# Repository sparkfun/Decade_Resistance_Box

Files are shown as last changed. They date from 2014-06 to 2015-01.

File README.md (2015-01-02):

Decade Resistance Box - KIT-13006
========================================

[Decade Resistance Box 
KIT-13006](https://www.sparkfun.com/products/13006)

This repository is for a decade resistance box kit, adjustable between 0 Ohms and 999,990 Ohms in 10 Ohm steps.  [More information can be found here.](https://www.sparkfun.com/products/13006)

Detailed information about building and using the decade resistance can be found it it's [hookup guide](https://learn.sparkfun.com/tutorials/decade-resistance-box-hookup-guide). 

This part was created in Eagle v6.5.0.  
The front panel etching/overlay was created with Inkscape 0.48.

Repository Contents
-------------------

* **/Hardware** - All Eagle design files (.brd, .sch, .STL)
* **/case-label** - The front panel markings in PDF and multi-layer SVG formats. 
* **/tutorial-images** - the sources for the images in the hookup guide. 

Product Versions
----------------
* [KIT-13006](https://www.sparkfun.com/products/13006)- Initial version of the kit PCBs.

Version History
---------------
* [ab37315990e0f04e8026698d327f7af8112845c8](https://github.com/sparkfun/Decade_Resistance_Box/commit/ab37315990e0f04e8026698d327f7af8112845c8) V10 PCB files 

License Information
-------------------
The hardware is released under [Creative Commons ShareAlike 4.0 International](https://creativecommons.org/licenses/by-sa/4.0/).

Distributed as-is; no warranty is given.

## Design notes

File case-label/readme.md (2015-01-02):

# Panel Legend Notes

Some notes on the contents of these files.

The original is the SVG, created using Inkscape  0.48.  It has many layers for the different elements and alignment marks.  You should be able to get the desired combination of markings by turning on and off the layers.

There have been some field reports about people having trouble opening the SVG, so the most important layers were also saved in a PDF, with the text converted to paths, to remove any dependency on having fonts installed.  Adobe Acrobat should be able to open and print the file - more capable tools (Illustrator, CorelDraw) should also be able to edit it.

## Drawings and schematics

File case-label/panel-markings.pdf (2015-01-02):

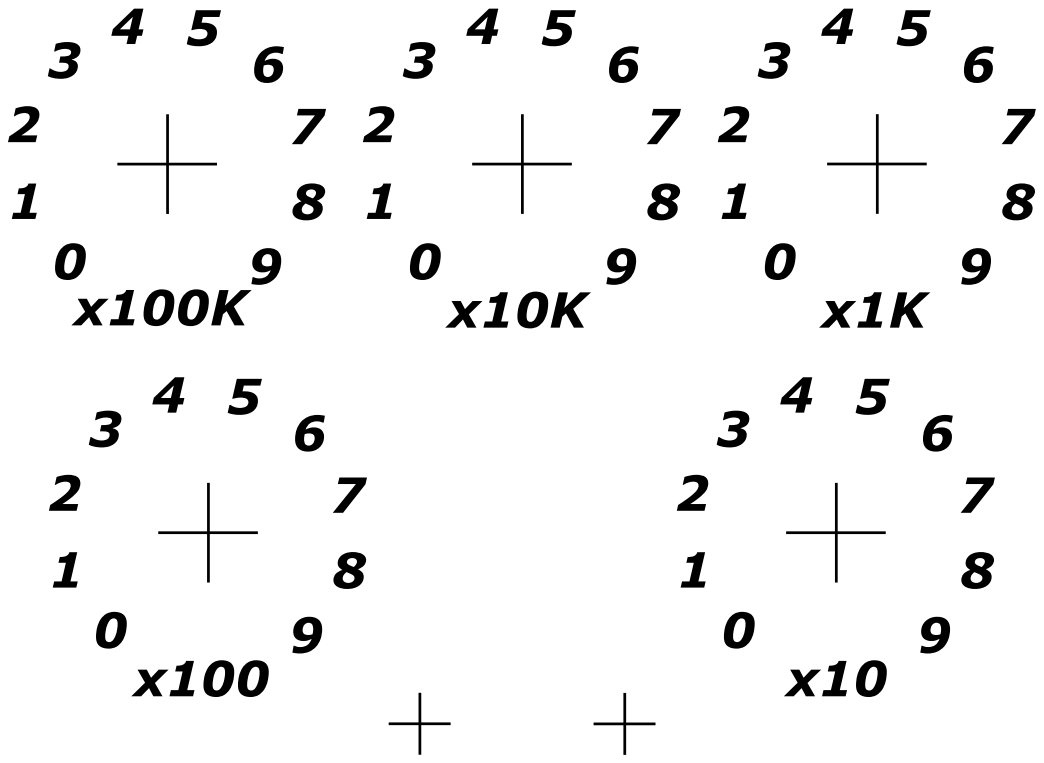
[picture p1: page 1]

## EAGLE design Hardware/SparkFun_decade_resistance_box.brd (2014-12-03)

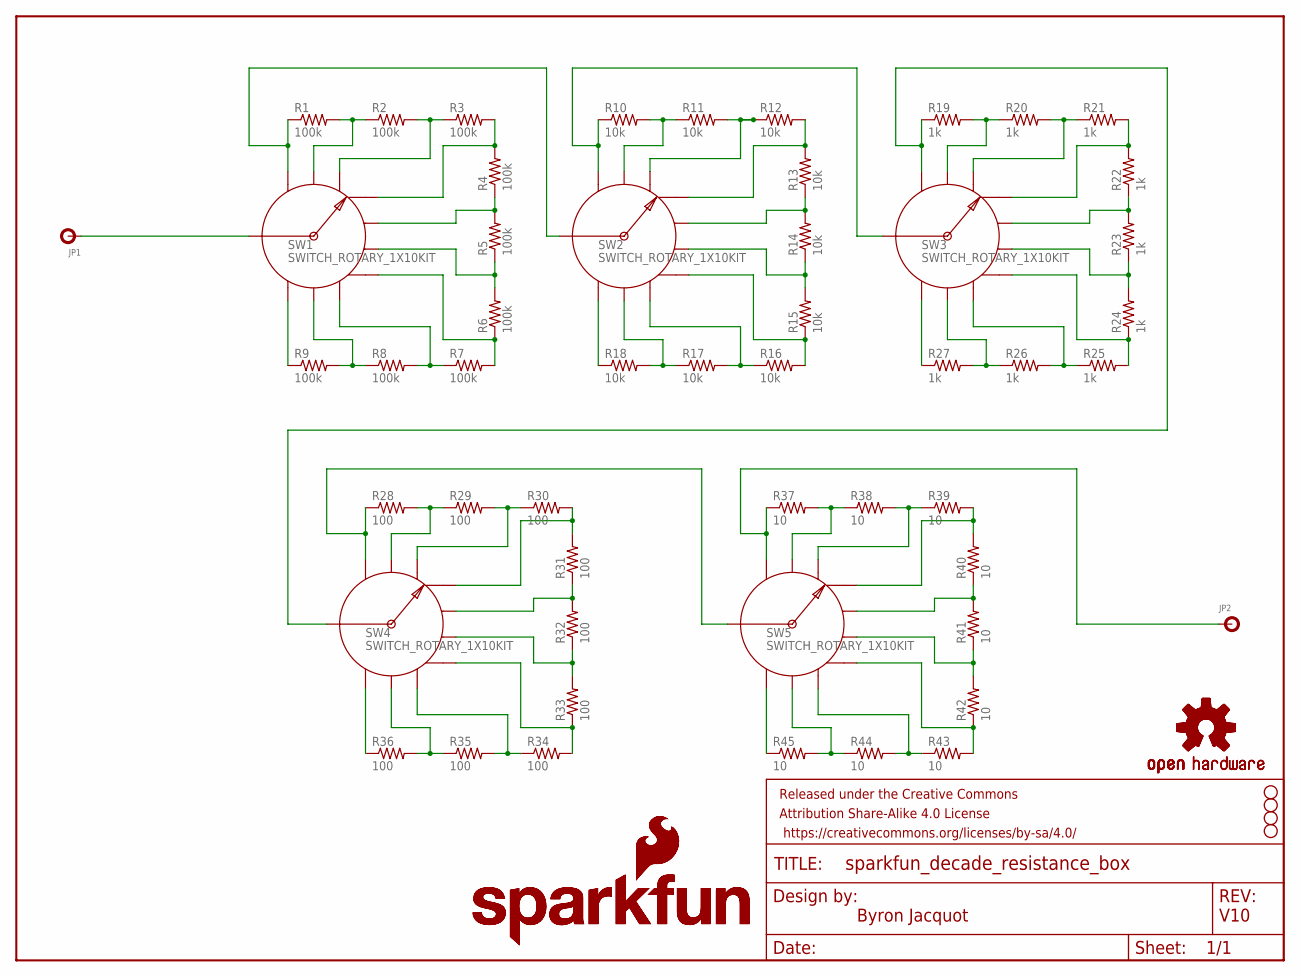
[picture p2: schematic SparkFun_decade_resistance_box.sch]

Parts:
FRAME1: FRAME-LETTER; CREATIVE_COMMONS
JP1, JP2: BANANA-JACK
LOGO1, LOGO4: OSHW-LOGOL; OSHW-LOGO-L
LOGO2: SFE_LOGO_NAME_FLAME.2_INCH; SFE_LOGO_NAME_FLAME_.2
LOGO3: SFE_LOGO_NAME_FLAME.5_INCH; SFE_LOGO_NAME_FLAME_.5
R1, R2, R3, R4, R5, R6, R7, R8, R9: 100k; AXIAL-0.1EZ
R10, R11, R12, R13, R14, R15, R16, R17, R18: 10k; AXIAL-0.1EZ
R19, R20, R21, R22, R23, R24, R25, R26, R27: 1k; AXIAL-0.1EZ
R28, R29, R30, R31, R32, R33, R34, R35, R36: 100; AXIAL-0.1EZ
R37, R38, R39, R40, R41, R42, R43, R44, R45: 10; AXIAL-0.1EZ
STANDOFF1, STANDOFF2, STANDOFF3, STANDOFF4: STAND-OFF
SW1, SW2, SW3, SW4, SW5: SWITCH_ROTARY_1X10KIT; ROTARY_SWITCH_1X10_KIT

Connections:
unnamed: R1.P$1 (1), SW1.1, SW2.COMMON
unnamed: R1.P$2 (2), R2.P$1 (1), SW1.2
unnamed: R2.P$2 (2), R3.P$1 (1), SW1.3
unnamed: R3.P$2 (2), R4.P$2 (2), SW1.4
unnamed: R4.P$1 (1), R5.P$2 (2), SW1.5
unnamed: R5.P$1 (1), R6.P$2 (2), SW1.6
unnamed: R6.P$1 (1), R7.P$2 (2), SW1.7
unnamed: R7.P$1 (1), R8.P$2 (2), SW1.8
unnamed: R8.P$1 (1), R9.P$2 (2), SW1.9
unnamed: R9.P$1 (1), SW1.10
unnamed: R10.P$1 (1), SW2.1, SW3.COMMON
unnamed: R10.P$2 (2), R11.P$1 (1), SW2.2
unnamed: R11.P$2 (2), R12.P$1 (1), SW2.3
unnamed: R12.P$2 (2), R13.P$2 (2), SW2.4
unnamed: R13.P$1 (1), R14.P$2 (2), SW2.5
unnamed: R14.P$1 (1), R15.P$2 (2), SW2.6
unnamed: JP1.P$1, SW1.COMMON
unnamed: R15.P$1 (1), R16.P$2 (2), SW2.7
unnamed: R16.P$1 (1), R17.P$2 (2), SW2.8
unnamed: R17.P$1 (1), R18.P$2 (2), SW2.9
unnamed: R18.P$1 (1), SW2.10
unnamed: R19.P$1 (1), SW3.1, SW4.COMMON
unnamed: R19.P$2 (2), R20.P$1 (1), SW3.2
unnamed: R20.P$2 (2), R21.P$1 (1), SW3.3
unnamed: R21.P$2 (2), R22.P$2 (2), SW3.4
unnamed: R22.P$1 (1), R23.P$2 (2), SW3.5
unnamed: R23.P$1 (1), R24.P$2 (2), SW3.6
unnamed: R24.P$1 (1), R25.P$2 (2), SW3.7
unnamed: R25.P$1 (1), R26.P$2 (2), SW3.8
unnamed: R26.P$1 (1), R27.P$2 (2), SW3.9
unnamed: R27.P$1 (1), SW3.10
unnamed: R28.P$1 (1), SW4.1, SW5.COMMON
unnamed: R28.P$2 (2), R29.P$1 (1), SW4.2
unnamed: R29.P$2 (2), R30.P$1 (1), SW4.3
unnamed: R30.P$2 (2), R31.P$2 (2), SW4.4
unnamed: R31.P$1 (1), R32.P$2 (2), SW4.5
unnamed: R32.P$1 (1), R33.P$2 (2), SW4.6
unnamed: R33.P$1 (1), R34.P$2 (2), SW4.7
unnamed: R34.P$1 (1), R35.P$2 (2), SW4.8
unnamed: R35.P$1 (1), R36.P$2 (2), SW4.9
unnamed: R36.P$1 (1), SW4.10
unnamed: JP2.P$1, R37.P$1 (1), SW5.1
unnamed: R37.P$2 (2), R38.P$1 (1), SW5.2
unnamed: R38.P$2 (2), R39.P$1 (1), SW5.3
unnamed: R39.P$2 (2), R40.P$2 (2), SW5.4
unnamed: R40.P$1 (1), R41.P$2 (2), SW5.5
unnamed: R41.P$1 (1), R42.P$2 (2), SW5.6
unnamed: R42.P$1 (1), R43.P$2 (2), SW5.7
unnamed: R43.P$1 (1), R44.P$2 (2), SW5.8
unnamed: R44.P$1 (1), R45.P$2 (2), SW5.9
unnamed: R45.P$1 (1), SW5.10

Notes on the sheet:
Byron Jacquot
V10

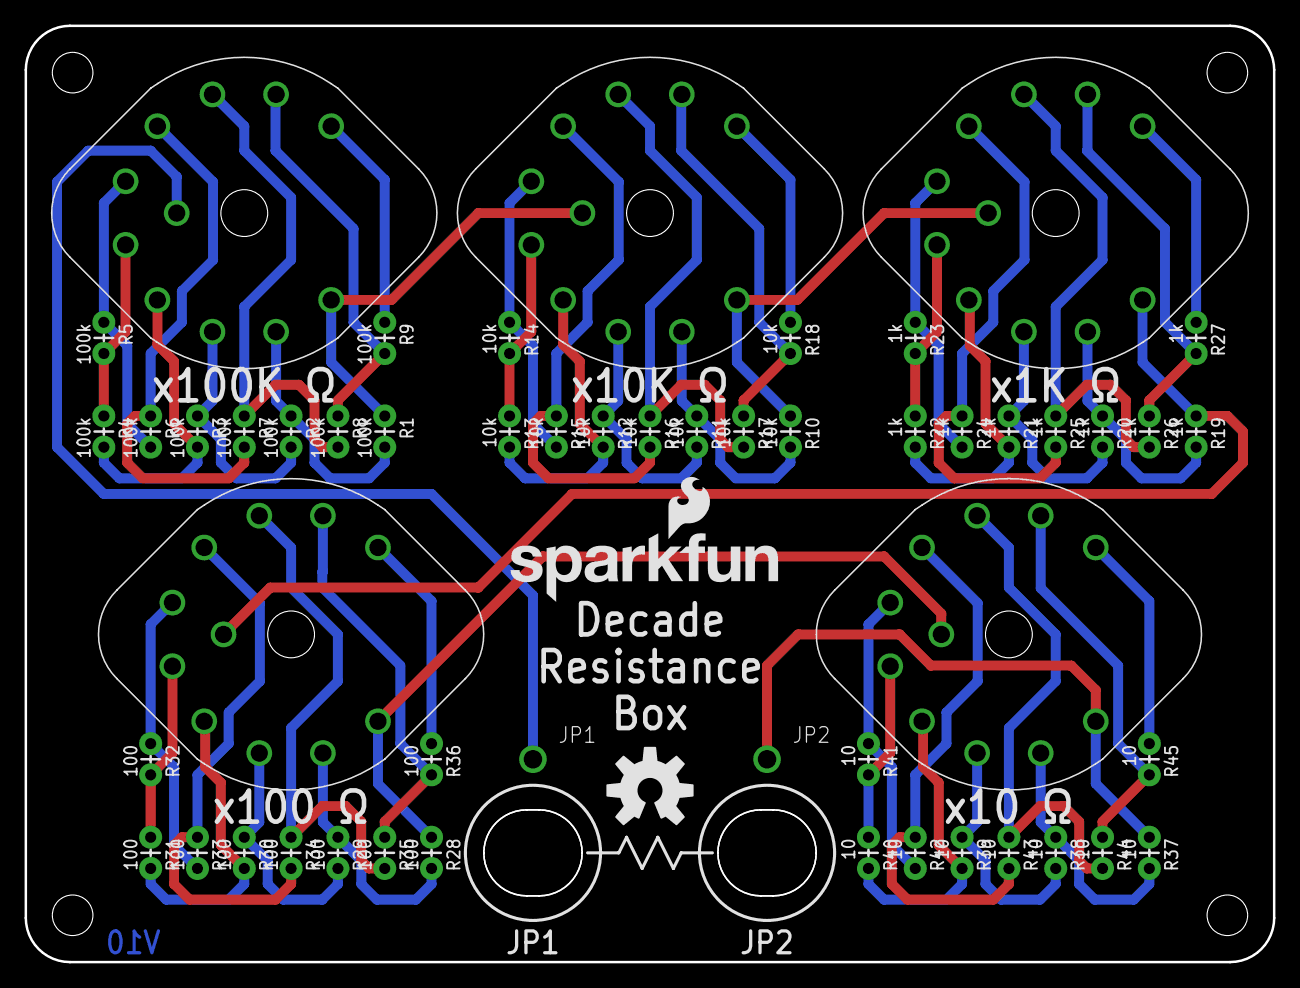
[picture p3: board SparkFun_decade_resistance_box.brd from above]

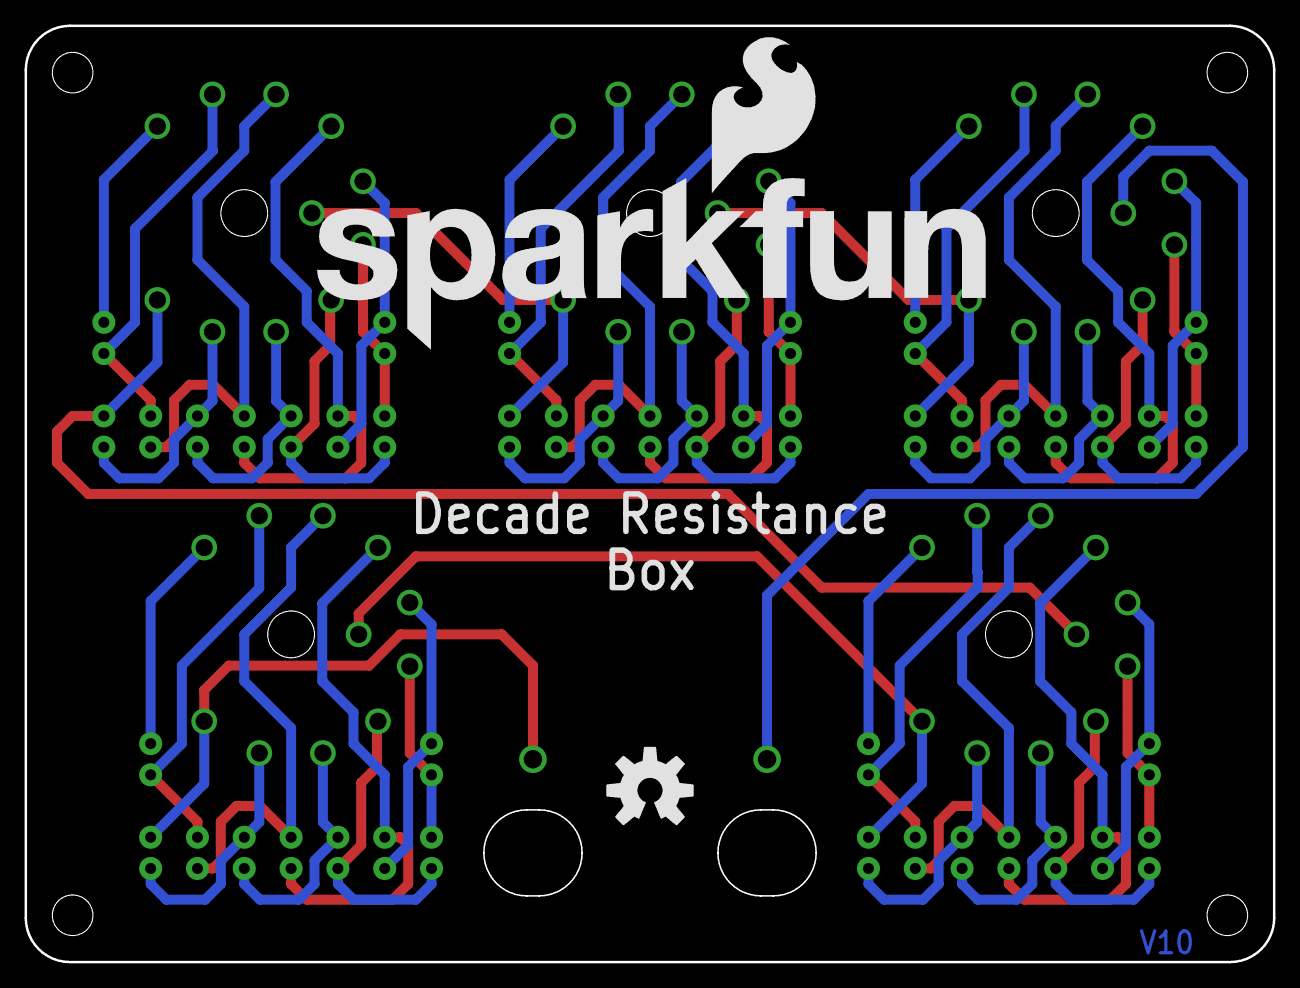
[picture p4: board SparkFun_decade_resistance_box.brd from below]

Board: 2 copper layers, 101.6 x 76.2 mm, 61 parts (2 on the bottom side), 51 nets.

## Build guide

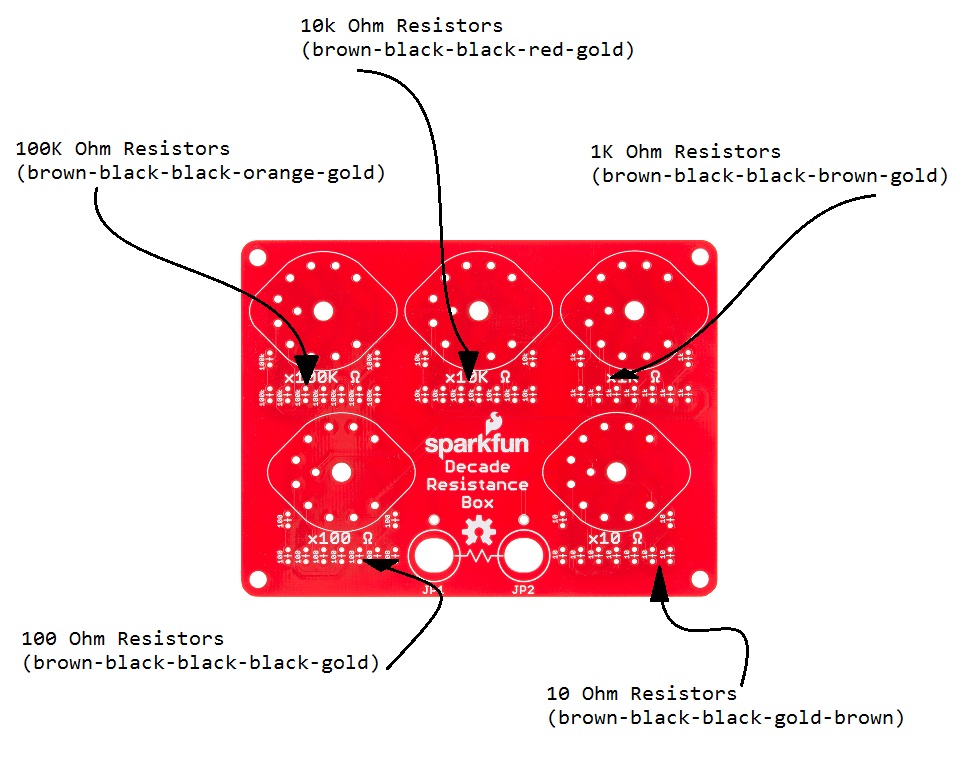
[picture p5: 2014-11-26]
tutorial-images/pcb-top-arrows.jpg

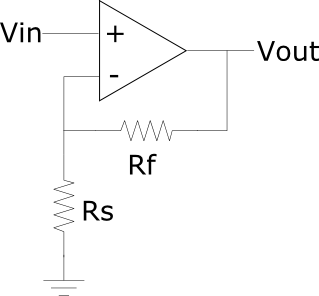
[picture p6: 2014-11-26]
tutorial-images/non-inv1.png

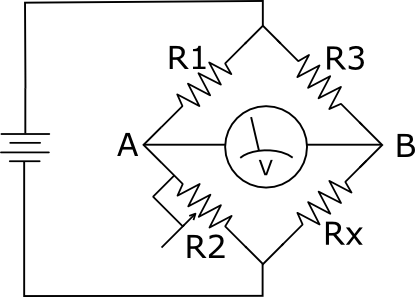
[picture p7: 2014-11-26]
tutorial-images/wheatstone.png

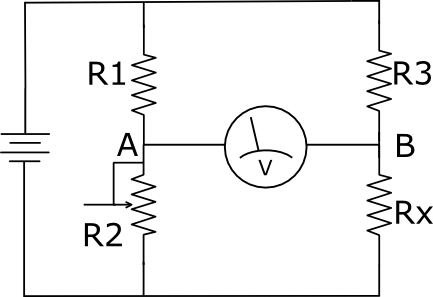
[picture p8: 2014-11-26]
tutorial-images/wheatstone-redrawn.png

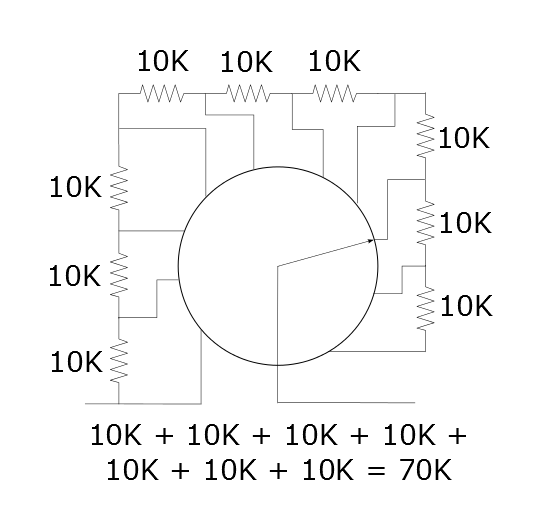
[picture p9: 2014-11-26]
tutorial-images/rotary.png

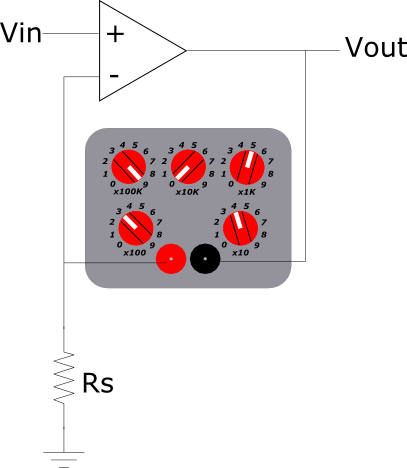
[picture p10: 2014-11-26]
tutorial-images/non-inv2.png

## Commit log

2014-06-27 Initial commit
    PCB and boilderplate files
    [decade_resistance.brd, decade_resistance.sch]
2014-06-30 Updated board after review
    [decade_resistance_box.brd, decade_resistance_box.sch]
2014-07-01 Moving to new 1% resistors
    [decade_resistance_box.brd, decade_resistance_box.sch]
2014-07-01 Updating rotaries
    Library part picked up PROD_ID and VALUE
    [decade_resistance_box.brd, decade_resistance_box.sch]
2014-07-01 One more library update for switches
    [decade_resistance_box.sch]
2014-08-05 Updates from Prototype review
    [decade_resistance_box.brd, decade_resistance_box.sch]
2014-08-11 Updates following redboard review
    Added a couple more dimension markings
    [decade_resistance_box.brd]
2014-12-03 Updating readme for product launch
    [SparkFun_decade_resistance_box.brd, SparkFun_decade_resistance_box.sch]
2015-01-02 Some updates to the case labels.
    Some users have reported trouble opening the SVG, so I also saved it as
    a printable PDF.

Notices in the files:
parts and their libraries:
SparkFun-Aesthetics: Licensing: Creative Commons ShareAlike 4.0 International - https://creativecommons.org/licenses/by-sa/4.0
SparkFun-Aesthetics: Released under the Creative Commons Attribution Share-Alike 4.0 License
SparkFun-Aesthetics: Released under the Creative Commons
